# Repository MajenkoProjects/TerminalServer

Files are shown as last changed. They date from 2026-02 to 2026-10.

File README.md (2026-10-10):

Open-source Terminal Server
===========================

This is a small 6 port serial terminal server with ethernet, USB and WiFi
connectivity.

**NOTE: THIS IS WORK IN PROGRESS AND NOT COMPLETE YET**

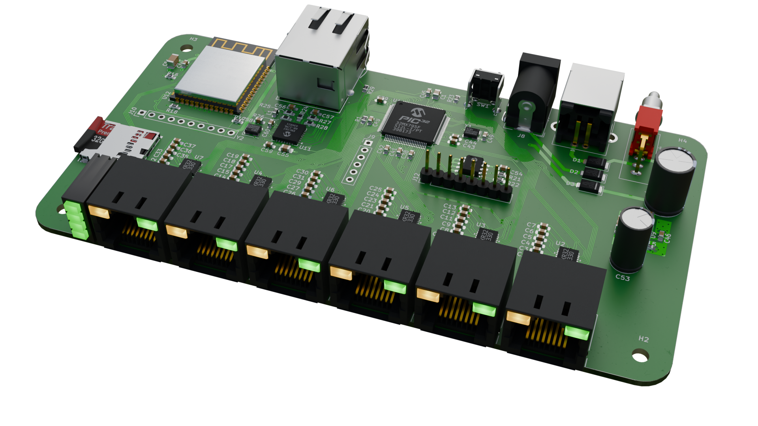
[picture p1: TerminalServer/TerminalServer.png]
Terminal Server


Current status:
---------------

* **Serial Ports:** Done
* **USB Ports:** Done
* **Ethernet:** Done
* **WiFi:** Done
* **Telnet in:** Done
* **Telnet out:** Done
* **TCP in:** Done
* **TU58 Emulation:** In Progress
* **TCP out:** Planned
* **PPP/SLIP:** Planned

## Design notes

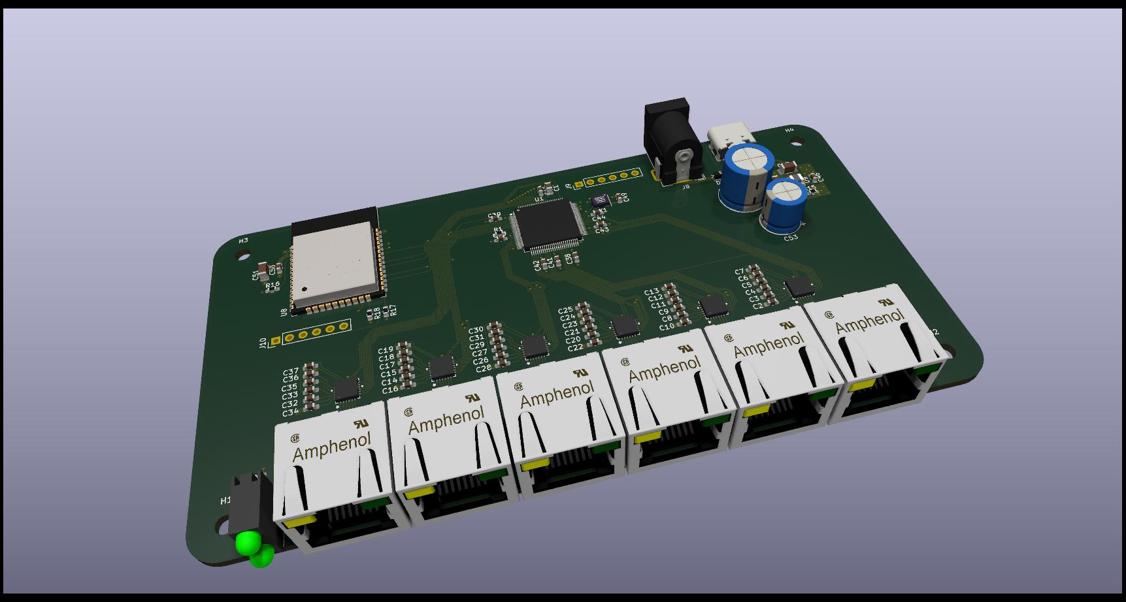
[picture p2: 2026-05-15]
TerminalServer/TerminalServer.jpg

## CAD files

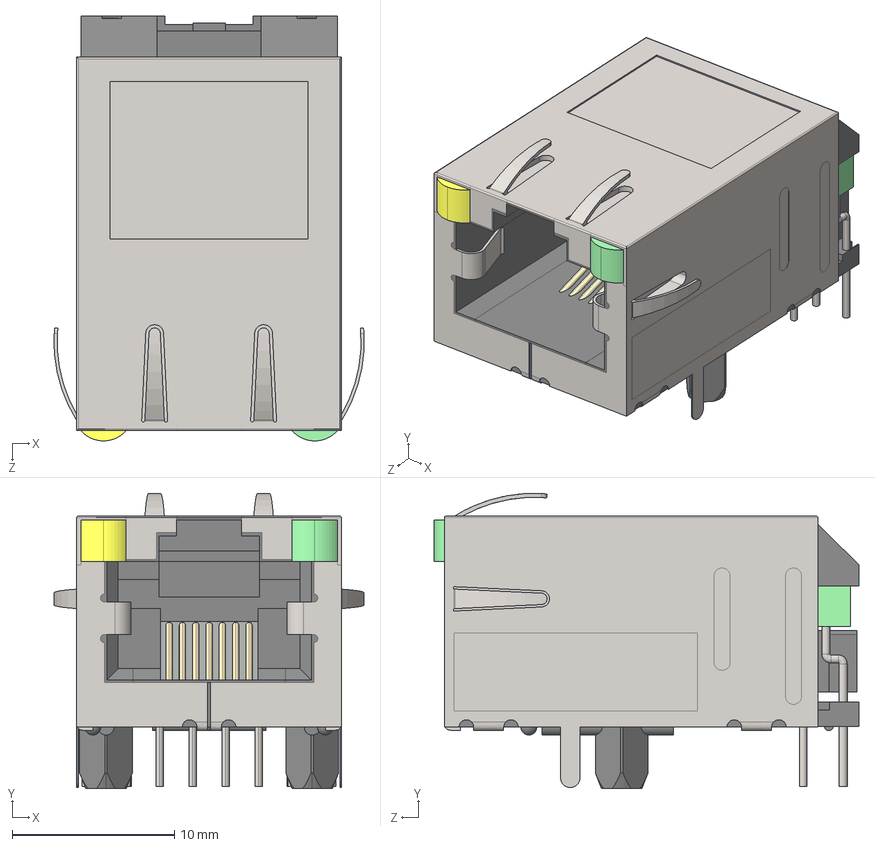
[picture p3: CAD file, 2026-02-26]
TerminalServer/Components/08B0-1D1T-06-F/3D/08B0-1D1T-06-F.stp
19.1 x 18.2 x 26.2 mm

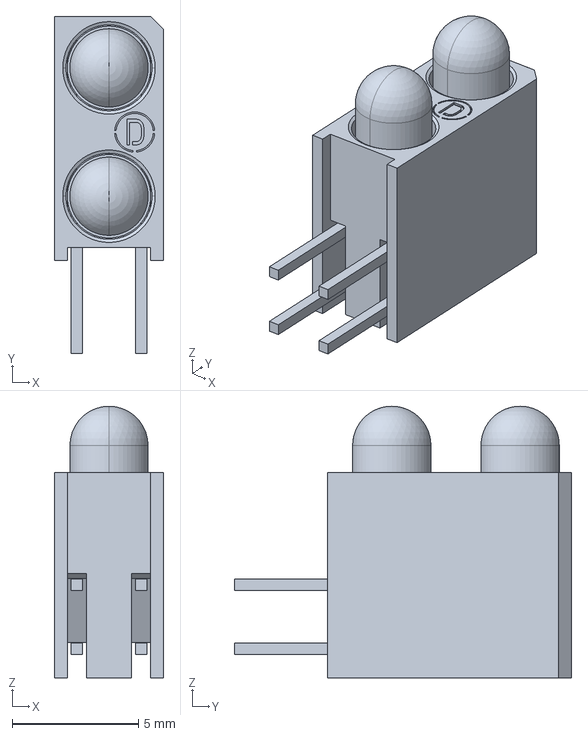
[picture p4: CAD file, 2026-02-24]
TerminalServer/Components/553-0121F/3D/553-0121F.stp
4.32 x 13.3 x 10.7 mm

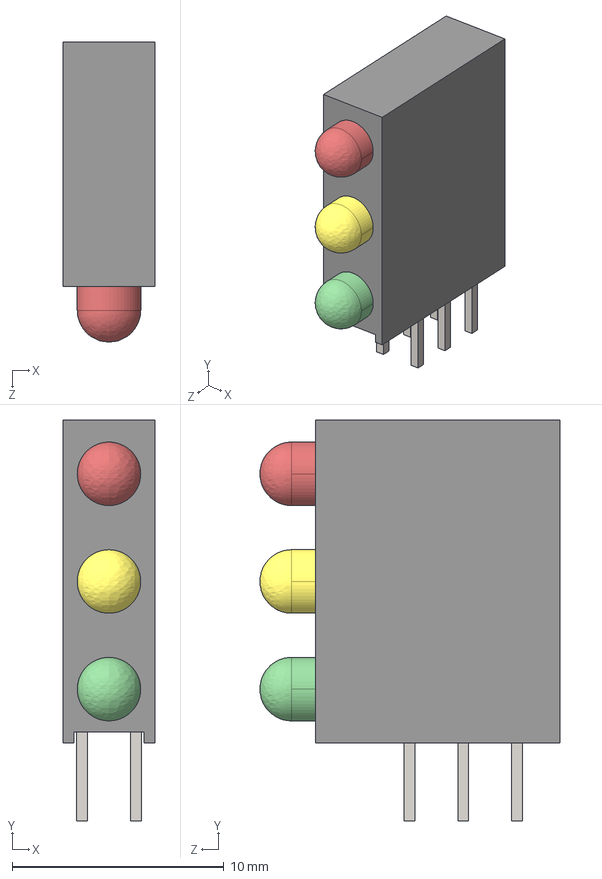
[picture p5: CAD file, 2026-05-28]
TerminalServer/Components/564-0100-132F/3D/564-0100-132F.stp
4.32 x 18.9 x 14.2 mm

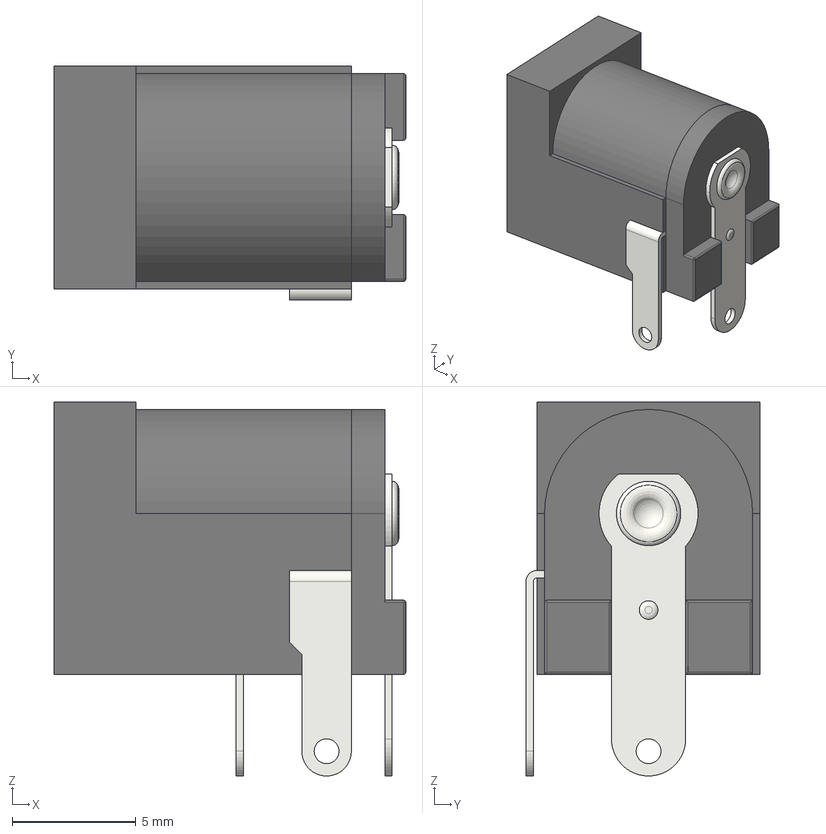
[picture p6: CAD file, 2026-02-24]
TerminalServer/Components/DC_Power_Jack_PCB_Mounted_2.1mm.step
14.2 x 9.45 x 15.1 mm
Plastic_Body_1of2
Plastic_Body_2of2
PIN_01
PIN_03
PIN_02
Boner

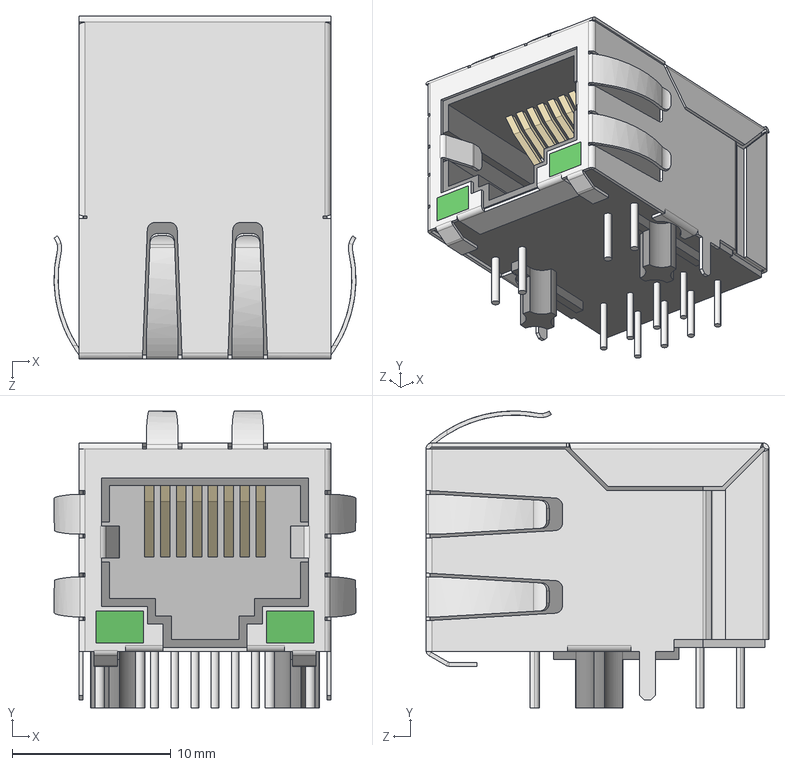
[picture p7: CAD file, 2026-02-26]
TerminalServer/Components/SI-60118-F/3D/SI-60118-F.stp
19.0 x 18.7 x 21.6 mm

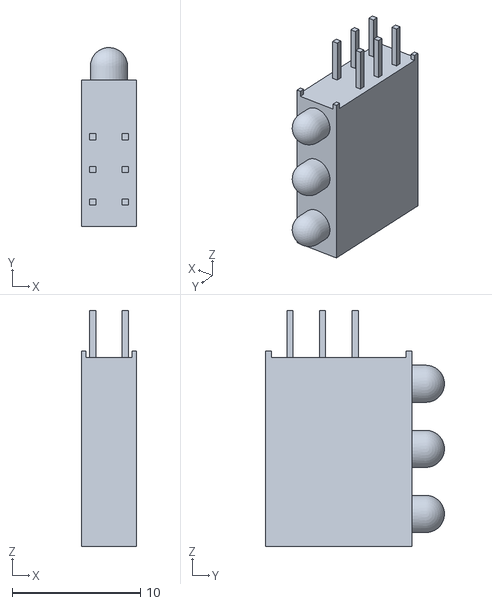
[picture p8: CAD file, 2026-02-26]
TerminalServer/Components/SSF-LXH340LYGID/3D/Unnamed-SSF-LXH340LYGID010.stl
4.32 x 14.0 x 18.4

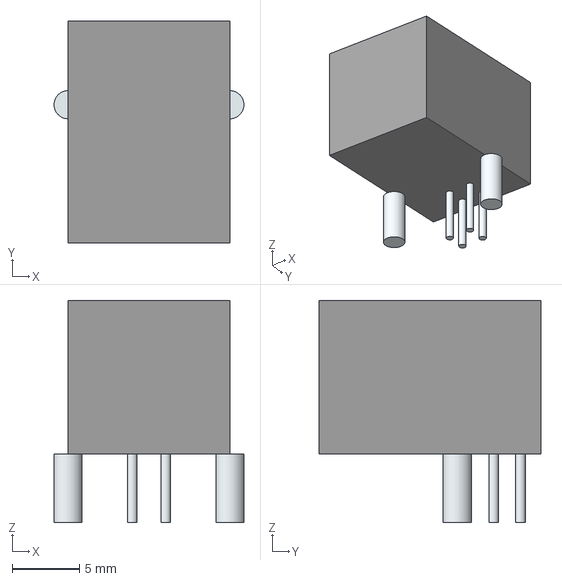
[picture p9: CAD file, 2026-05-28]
TerminalServer/Components/USB-B-S-RA-WT-SPCC/3D/USB-B-S-RA-WT-SPCC.stp
14.1 x 16.5 x 16.5 mm
Leads

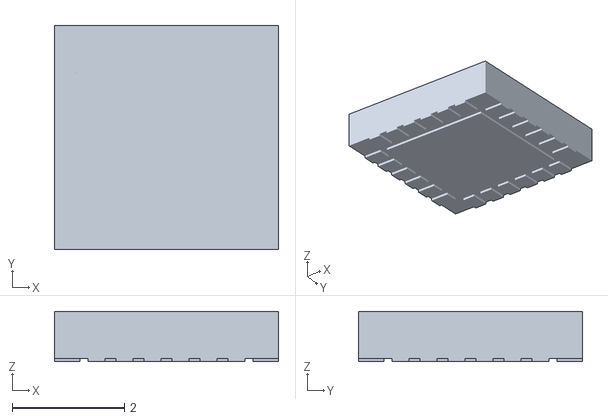
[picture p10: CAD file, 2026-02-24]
TerminalServer/Components/Unnamed-QFN_24.stl
3.99 x 3.99 x 0.892

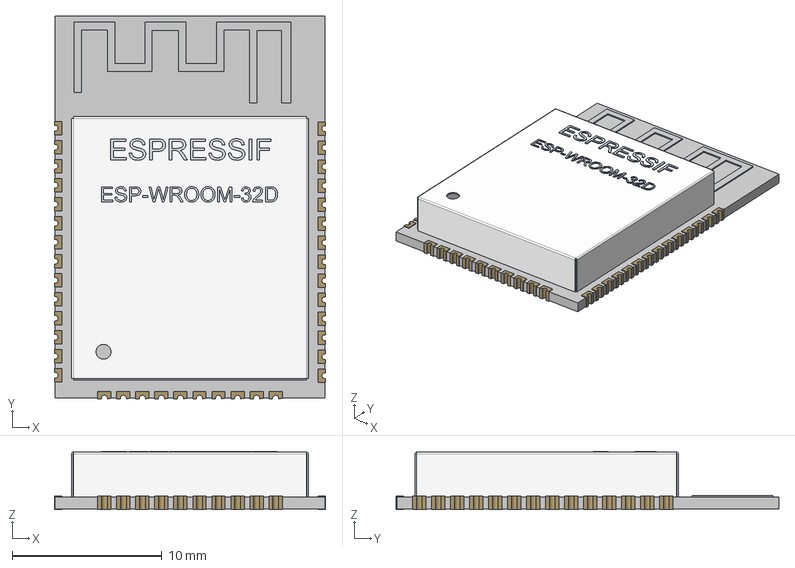
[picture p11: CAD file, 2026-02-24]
TerminalServer/Components/esp32_wroom_32D_module.step
18.1 x 25.6 x 3.90 mm
PCB_mince
Text_ESP32
Text_ESP033
Text_ESP034
Text_ESP035
Text_ESP036
Text_ESP037
Text_ESP038
Text_ESP039
Text_ESP040
Text_ESP041
Text_ESP042
Text_ESP043
Text_ESP044
Text_Espressif
Text_Espressif001
Text_Espressif002
Text_Espressif003
Text_Espressif004
Text_Espressif005
Text_Espressif006
Text_Espressif007
Text_Espressif008
pin_001 x 10
pin_011 x 14
pin_026 x 14

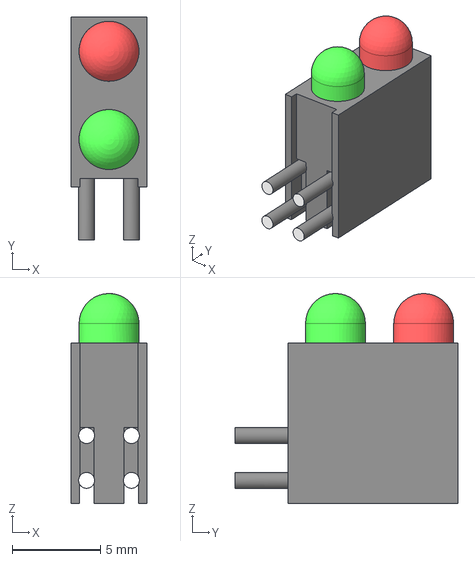
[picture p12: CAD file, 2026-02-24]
TerminalServer/Components/DUAL LED HOUSING 3mm.stp
4.32 x 12.7 x 11.9 mm

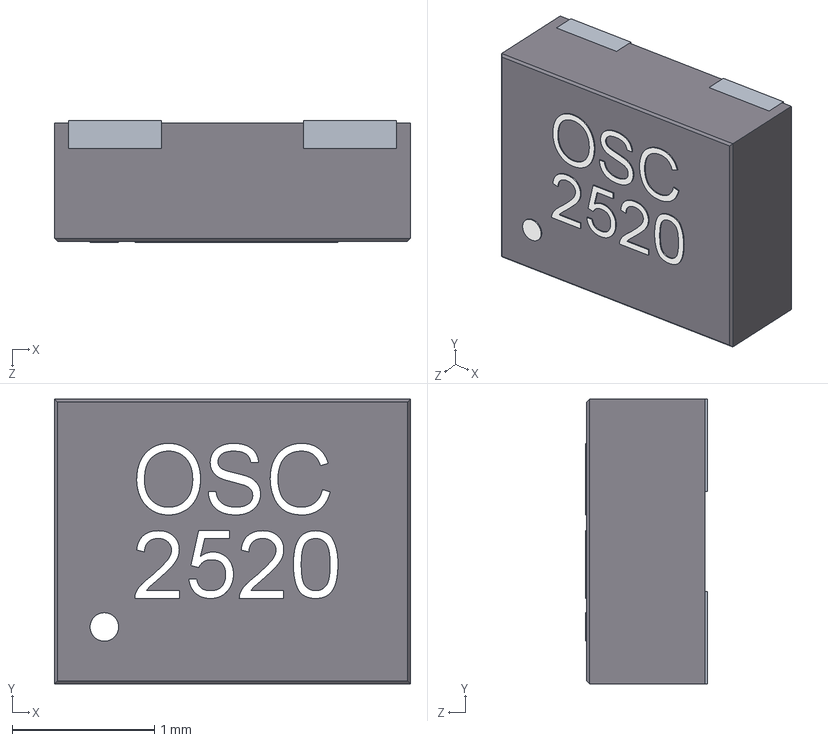
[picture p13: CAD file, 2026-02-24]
TerminalServer/Components/User Library-Oscillator2520-4pol-1.STEP
2.50 x 2.00 x 0.86 mm
Zylinder

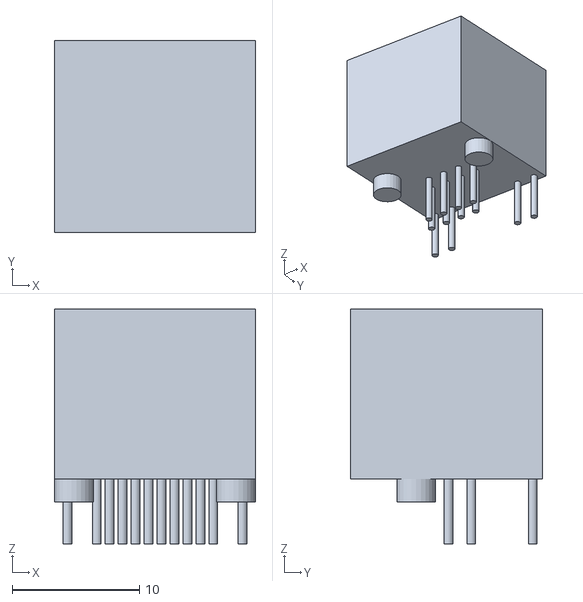
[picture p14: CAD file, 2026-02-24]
TerminalServer/Components/Unnamed-MTJ_88ARX1_LH.stl
15.8 x 15.1 x 18.4

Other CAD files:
TerminalServer/Components/553-0121F/3D/Unnamed-5530XXXF_SW0001.stl
TerminalServer/Components/SSF-LXH340LYGID/3D/SSF-LXH340LYGID.stp
TerminalServer/Components/Unnamed-DC_Power_Jack_PCB_Mounted_2.1mm.stl
TerminalServer/Components/esp32_wr_32_logo_module.step
TerminalServer/Components/QFN-24.iges
TerminalServer/Components/MTJ-88ARX1-LH.igs
TerminalServer/Components/12401610E4#2A/3D/12401610E4#2A.stl
TerminalServer/Components/12401610E4#2A/3D/12401610E4#2A.stp
TerminalServer/Components/217175-0001/3D/217175-0001.stl
TerminalServer/Components/217175-0001/3D/217175-0001.stp
TerminalServer/Components/503398-1892/3D/503398-1892.stl
TerminalServer/Components/503398-1892/3D/503398-1892.stp
TerminalServer/Components/564-0100-132F/3D/564-0100-132F.stl
TerminalServer/Components/TPS82130SILR.stp
TerminalServer/Components/USB-B-S-RA-WT-SPCC/3D/USB-B-S-RA-WT-SPCC.stl

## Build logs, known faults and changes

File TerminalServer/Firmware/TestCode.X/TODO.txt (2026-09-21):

Ports

    UART                Done
    USB                 Done
    Telnet In           Done
    Telnet Out          Done
    TCP In              Done
    TCP Out
    UDP In
    UDP Out

Functions

    Set terminal type (and map to tinfo)                    Done
    Set terminal local/forward/backward keys                Done
    Service definitions (name->port(s), name->telnet)
    Help

Misc

    Factory reset on hold button                            Done (30 second hold time)
    Bootloaderifcation
    mDNS                                                    Done (at least hostname is)

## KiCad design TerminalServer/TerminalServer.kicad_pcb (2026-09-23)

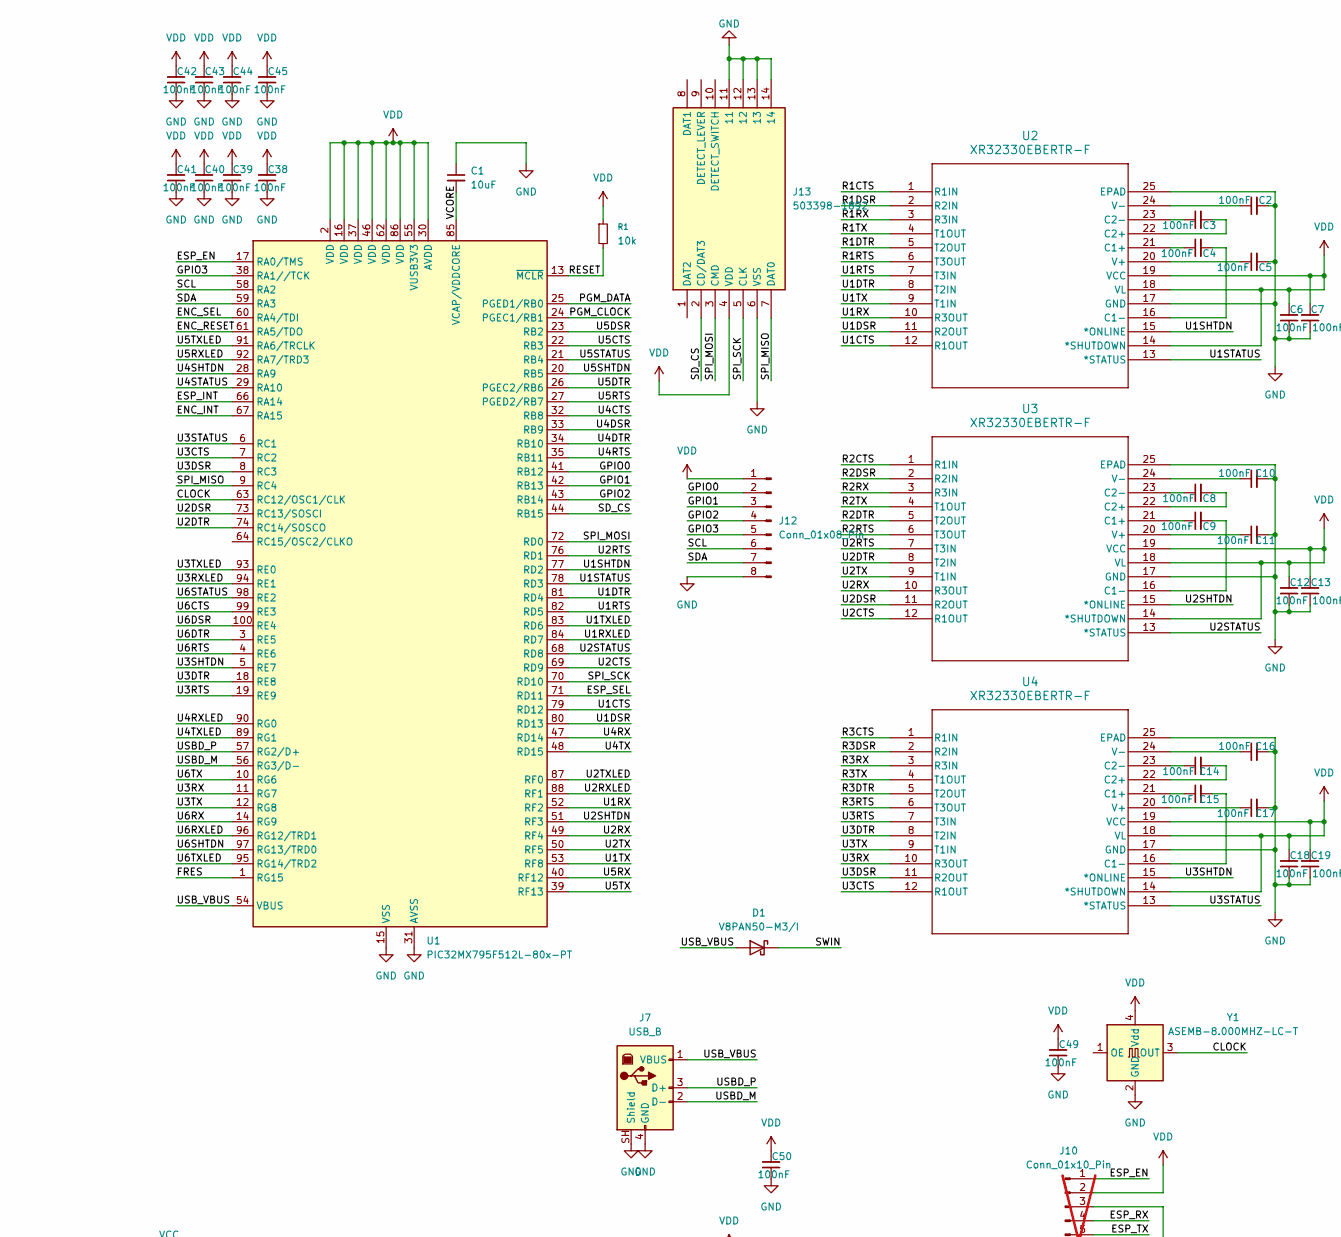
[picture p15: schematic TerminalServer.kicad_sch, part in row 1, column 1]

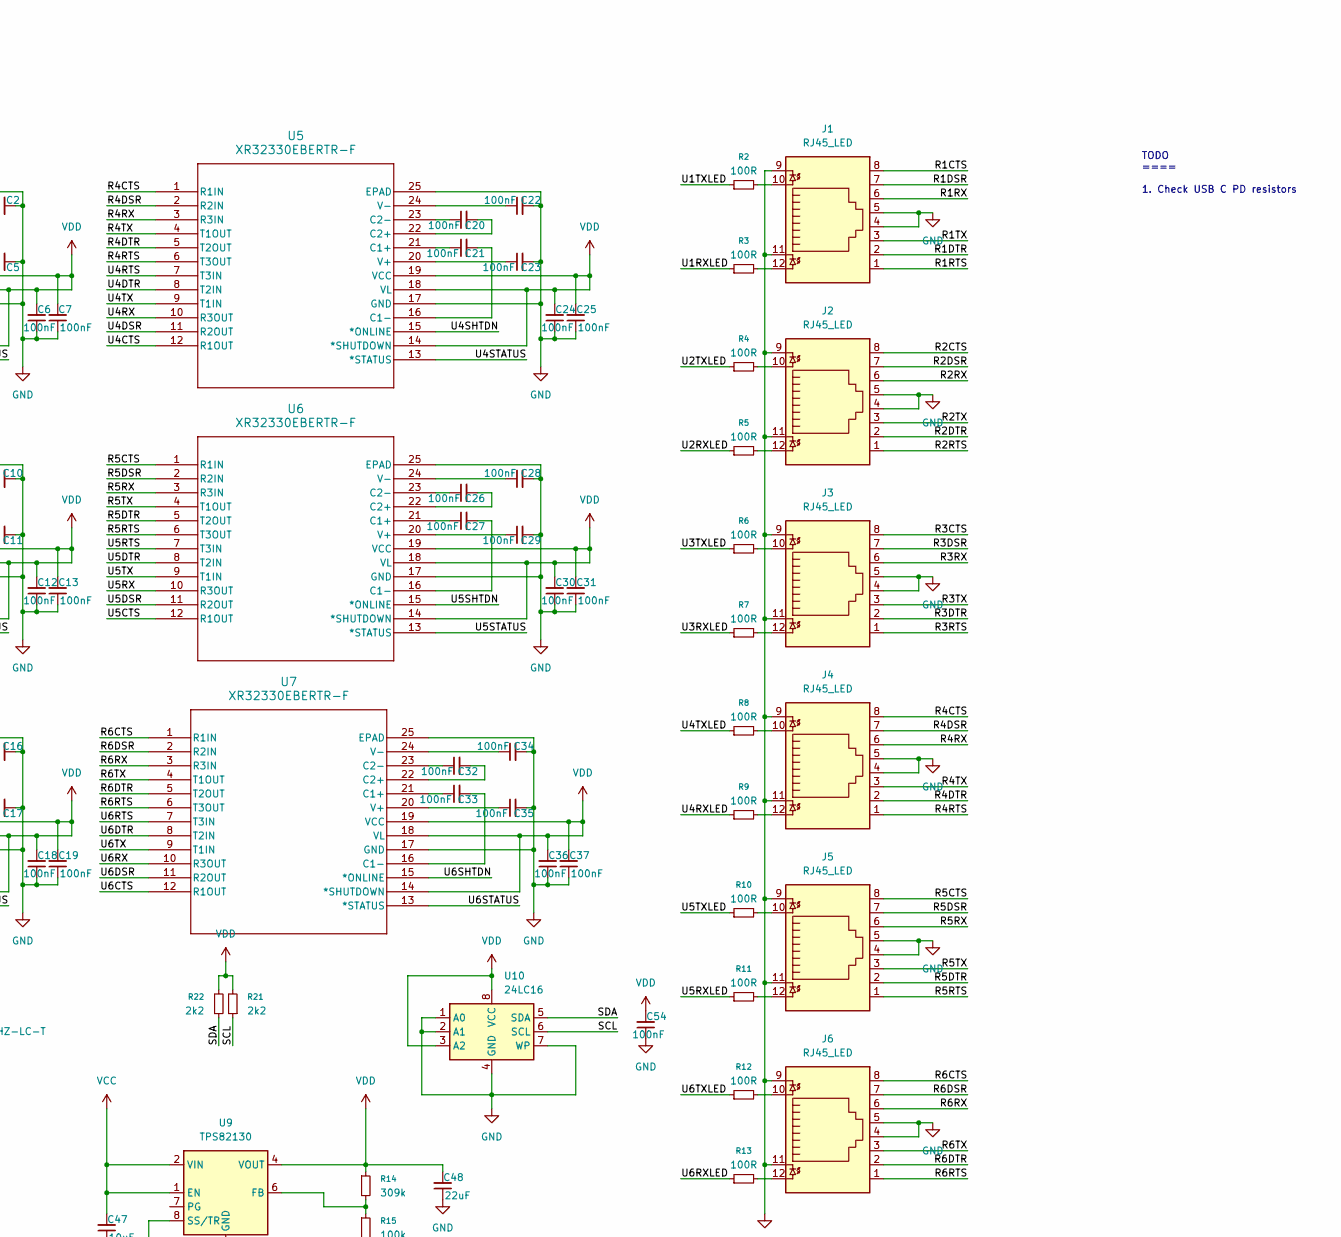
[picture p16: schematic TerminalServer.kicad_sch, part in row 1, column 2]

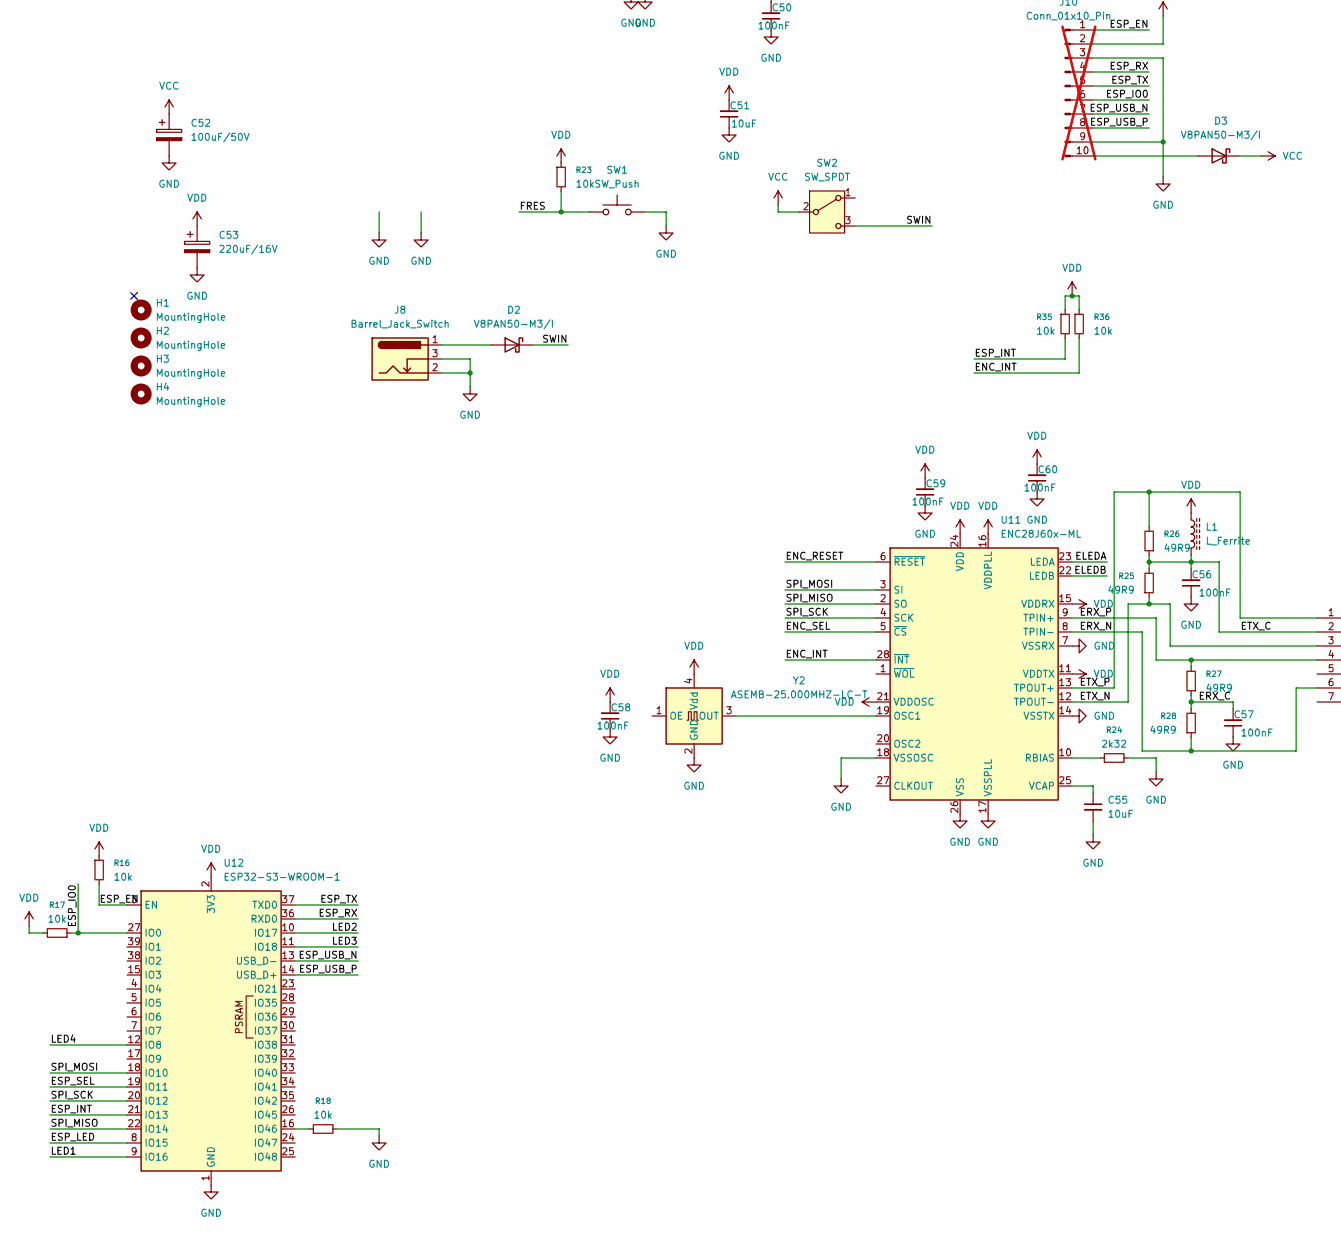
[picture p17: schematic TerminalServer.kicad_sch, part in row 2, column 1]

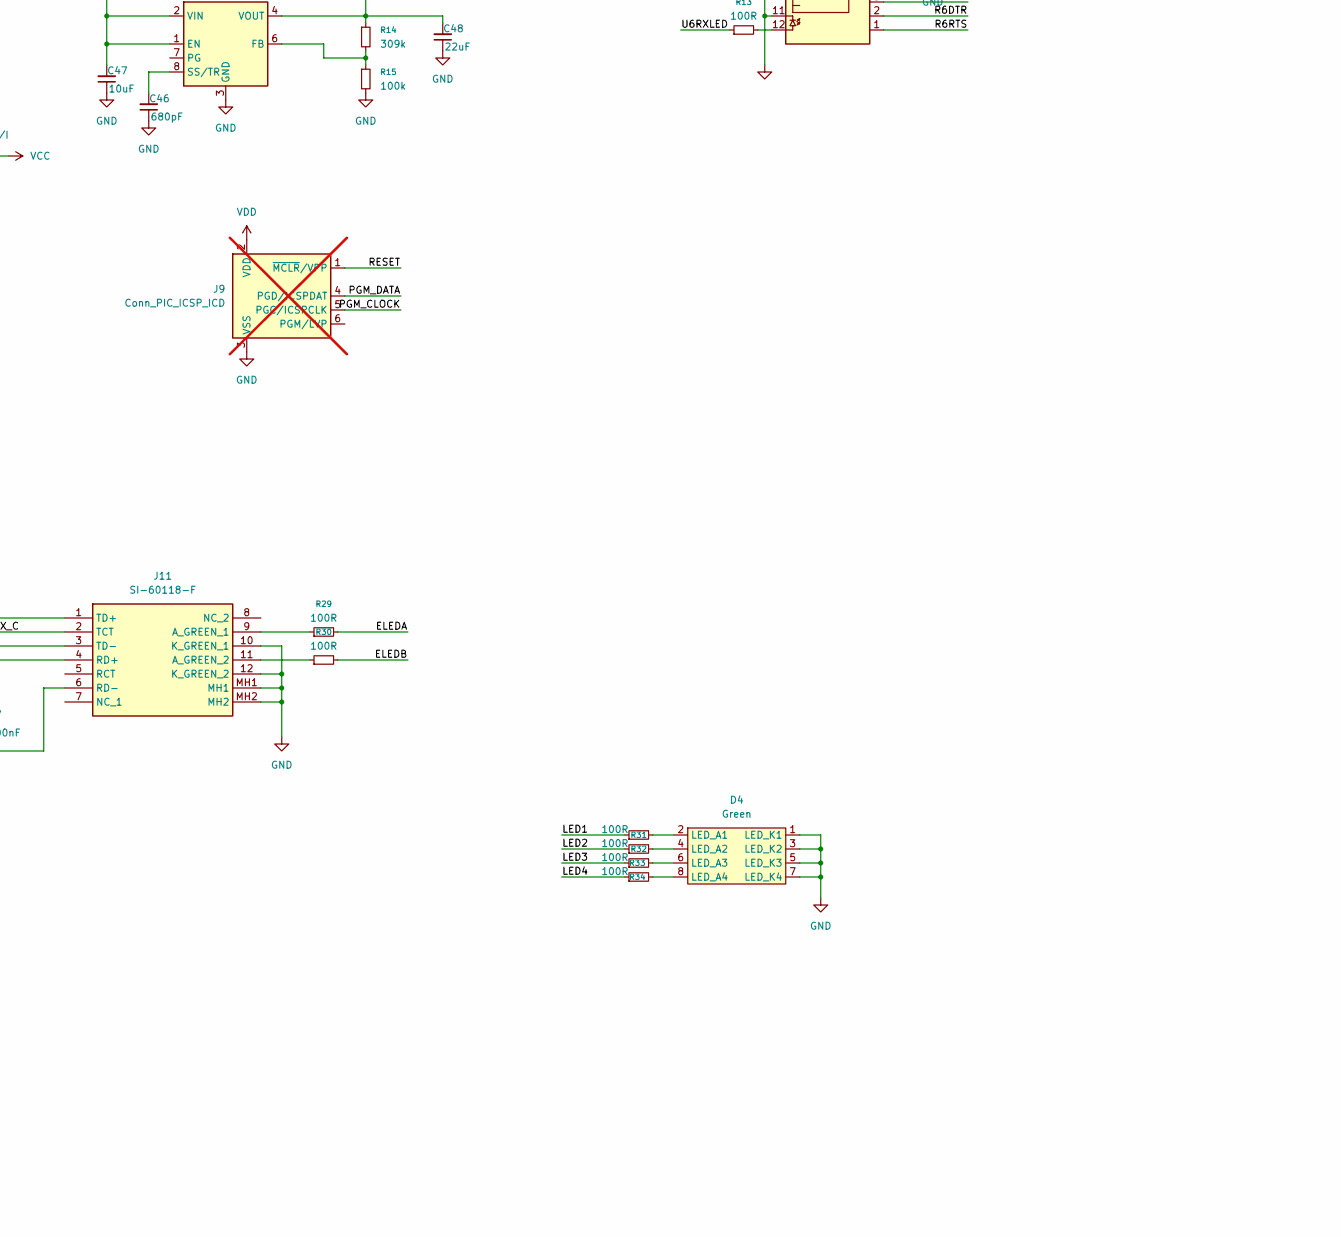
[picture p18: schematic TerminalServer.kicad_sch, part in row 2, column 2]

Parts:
C1, C55: 10uF; C_0805_2012Metric_Pad1.18x1.45mm_HandSolder
C2, C3, C4, C5, C6, C7, C8, C9, C10, C11, C12, C13, C14, C15, C16, C17, C18, C19, C20, C21, C22, C23, C24, C25, C26, C27, C28, C29, C30, C31, C32, C33, C34, C35, C36, C37, C38, C39, C40, C41, C42, C43, C44, C45, C49, C50, C54, C56, C57, C58, C59, C60: 100nF; C_0603_1608Metric_Pad1.08x0.95mm_HandSolder
C46: 680pF; C_0603_1608Metric_Pad1.08x0.95mm_HandSolder
C47, C51: 10uF; C_1206_3216Metric
C48: 22uF; C_1206_3216Metric
C52: 100uF/50V; CP_Radial_D8.0mm_P3.50mm; Part ESK107M050AG3AA
C53: 220uF/16V; CP_Radial_D6.3mm_P2.50mm; Part ESK227M016AE3EA
D1, D2, D3: V8PAN50-M3/I; Vishay_SMPA; Mouser 78-V8PAN50-M3/I
D4: Green; XL-DZ234SYGD-4; Mouser 604-WP914CK4GDT
H1, H2, H3, H4: MountingHole; MountingHole_3.2mm_M3
J1, J2, J3, J4, J5, J6: RJ45_LED; RJ45_MTJ-88ARX1-LH_ADM; Mouser 737-MTJ-88ARX1-LH
J7: USB_B; USB_B_OST_USB-B1HSxx_Horizontal; Mouser 200-USBBSFBTHFR
J8: Barrel_Jack_Switch; BarrelJack_Wuerth_6941xx301002; Mouser 710-694106301002
J9: Conn_PIC_ICSP_ICD; PinHeader_1x06_P2.54mm_Vertical; not fitted
J10: Conn_01x10_Pin; PinHeader_1x10_P2.54mm_Vertical; not fitted
J11: SI-60118-F; SI60118F; Mouser Part Number 530-SI-60118-F
J12: Conn_01x08_Pin; PinHeader_1x08_P2.54mm_Vertical
J13: 503398-1892; 5033981892; Mouser Part Number 538-503398-1892
L1: L_Ferrite; L_0603_1608Metric_Pad1.05x0.95mm_HandSolder
R1, R16, R17, R18, R23, R35, R36: 10k; R_0603_1608Metric_Pad0.98x0.95mm_HandSolder
R2, R3, R4, R5, R6, R7, R8, R9, R10, R11, R12, R13, R29, R30, R31, R32, R33, R34: 100R; R_0603_1608Metric_Pad0.98x0.95mm_HandSolder
R14: 309k; R_0603_1608Metric_Pad0.98x0.95mm_HandSolder
R15: 100k; R_0603_1608Metric_Pad0.98x0.95mm_HandSolder
R21, R22: 2k2; R_0603_1608Metric_Pad0.98x0.95mm_HandSolder
R24: 2k32; R_0603_1608Metric_Pad0.98x0.95mm_HandSolder
R25, R26, R27, R28: 49R9; R_0603_1608Metric_Pad0.98x0.95mm_HandSolder
SW1: SW_Push; SW_Tactile_SPST_Angled_PTS645Vx31-2LFS
SW2: SW_SPDT; 34ASP23B4M7RT
U1: PIC32MX795F512L-80x-PT; TQFP-100_12x12mm_P0.4mm; Mouser 579-PIC32MX795F512
U2, U3, U4, U5, U6, U7: XR32330EBERTR-F; QFN-24; Mouser 701-XR32330EBERTR-F
U9: TPS82130; Texas_SIL0008D_MicroSiP-8-1EP_2.8x3mm_P0.65mm_EP1.1x1.9mm_T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
U10: 24LC16; SOIC-8_3.9x4.9mm_P1.27mm
U11: ENC28J60x-ML; QFN-28-1EP_6x6mm_P0.65mm_EP4.25x4.25mm
U12: ESP32-S3-WROOM-1
Y1: ASEMB-8.000MHZ-LC-T; Oscillator_SMD_SiT_PQFN-4Pin_3.2x2.5mm
Y2: ASEMB-25.000MHZ-LC-T; Oscillator_SMD_SiT_PQFN-4Pin_3.2x2.5mm

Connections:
/CLOCK: U1.63 (RC12/OSC1/CLK), Y1.3 (OUT)
/ELEDA: R29.2, U11.23 (LEDA)
/ELEDB: R30.2, U11.22 (LEDB)
/ENC_INT: R36.2, U1.67 (RA15), U11.28 (~INT)
/ENC_RESET: U1.61 (RA5/TDO), U11.6 (~RESET)
/ENC_SEL: U1.60 (RA4/TDI), U11.5 (~CS)
/ERX_C: C57.2, R27.1, R28.2
/ERX_N: J11.6 (RD-), R28.1, U11.8 (TPIN-)
/ERX_P: J11.4 (RD+), R27.2, U11.9 (TPIN+)
/ESP_EN: J10.1, R16.2, U1.17 (RA0/TMS), U12.3 (EN)
/ESP_INT: R35.2, U1.66 (RA14), U12.21 (IO13)
/ESP_IO0: J10.6, R17.1, U12.27 (IO0)
/ESP_LED: U12.8 (IO15)
/ESP_RX: J10.4, U12.36 (RXD0)
/ESP_SEL: U1.71 (RD11), U12.19 (IO11)
/ESP_TX: J10.5, U12.37 (TXD0)
/ESP_USB_N: J10.7, U12.13 (USB_D-)
/ESP_USB_P: J10.8, U12.14 (USB_D+)
/ETX_C: C56.2, J11.2 (TCT), L1.2, R25.2, R26.1
/ETX_N: J11.3 (TD-), R25.1, U11.12 (TPOUT-)
/ETX_P: J11.1 (TD+), R26.2, U11.13 (TPOUT+)
/FRES: R23.2, SW1.1, U1.1 (RG15)
/GPIO0: J12.2, U1.41 (RB12)
/GPIO1: J12.3, U1.42 (RB13)
/GPIO2: J12.4, U1.43 (RB14)
/GPIO3: J12.5, U1.38 (RA1//TCK)
/LED1: R31.1, U12.9 (IO16)
/LED2: R32.1, U12.10 (IO17)
/LED3: R33.1, U12.11 (IO18)
/LED4: R34.1, U12.12 (IO8)
/PGM_CLOCK: J9.5 (PGC/ICSPCLK), U1.24 (PGEC1/RB1)
/PGM_DATA: J9.4 (PGD/ICSPDAT), U1.25 (PGED1/RB0)
/R1CTS: J1.8, U2.1 (R1IN)
/R1DSR: J1.7, U2.2 (R2IN)
/R1DTR: J1.2, U2.5 (T2OUT)
/R1RTS: J1.1, U2.6 (T3OUT)
/R1RX: J1.6, U2.3 (R3IN)
/R1TX: J1.3, U2.4 (T1OUT)
/R2CTS: J2.8, U3.1 (R1IN)
/R2DSR: J2.7, U3.2 (R2IN)
/R2DTR: J2.2, U3.5 (T2OUT)
/R2RTS: J2.1, U3.6 (T3OUT)
/R2RX: J2.6, U3.3 (R3IN)
/R2TX: J2.3, U3.4 (T1OUT)
/R3CTS: J3.8, U4.1 (R1IN)
/R3DSR: J3.7, U4.2 (R2IN)
/R3DTR: J3.2, U4.5 (T2OUT)
/R3RTS: J3.1, U4.6 (T3OUT)
/R3RX: J3.6, U4.3 (R3IN)
/R3TX: J3.3, U4.4 (T1OUT)
/R4CTS: J4.8, U5.1 (R1IN)
/R4DSR: J4.7, U5.2 (R2IN)
/R4DTR: J4.2, U5.5 (T2OUT)
/R4RTS: J4.1, U5.6 (T3OUT)
/R4RX: J4.6, U5.3 (R3IN)
/R4TX: J4.3, U5.4 (T1OUT)
/R5CTS: J5.8, U6.1 (R1IN)
/R5DSR: J5.7, U6.2 (R2IN)
/R5DTR: J5.2, U6.5 (T2OUT)
/R5RTS: J5.1, U6.6 (T3OUT)
/R5RX: J5.6, U6.3 (R3IN)
/R5TX: J5.3, U6.4 (T1OUT)
/R6CTS: J6.8, U7.1 (R1IN)
/R6DSR: J6.7, U7.2 (R2IN)
/R6DTR: J6.2, U7.5 (T2OUT)
/R6RTS: J6.1, U7.6 (T3OUT)
/R6RX: J6.6, U7.3 (R3IN)
/R6TX: J6.3, U7.4 (T1OUT)
/RESET: J9.1 (~MCLR/VPP), R1.2, U1.13 (~MCLR)
/SCL: J12.6, R21.1, U1.58 (RA2), U10.6 (SCL)
/SDA: J12.7, R22.1, U1.59 (RA3), U10.5 (SDA)
/SD_CS: J13.2 (CD/DAT3), U1.44 (RB15)
/SPI_MISO: J13.7 (DAT0), U1.9 (RC4), U11.2 (SO), U12.22 (IO14)
/SPI_MOSI: J13.3 (CMD), U1.72 (RD0), U11.3 (SI), U12.18 (IO10)
/SPI_SCK: J13.5 (CLK), U1.70 (RD10), U11.4 (SCK), U12.20 (IO12)
/SWIN: D1.1 (K), D2.1 (K), SW2.3 (C)
/U1CTS: U1.79 (RD12), U2.12 (R1OUT)
/U1DSR: U1.80 (RD13), U2.11 (R2OUT)
/U1DTR: U1.81 (RD4), U2.8 (T2IN)
/U1RTS: U1.82 (RD5), U2.7 (T3IN)
/U1RX: U1.52 (RF2), U2.10 (R3OUT)
/U1RXLED: R3.1, U1.84 (RD7)
/U1SHTDN: U1.77 (RD2), U2.15 (*ONLINE)
/U1STATUS: U1.78 (RD3), U2.13 (*STATUS)
/U1TX: U1.53 (RF8), U2.9 (T1IN)
/U1TXLED: R2.1, U1.83 (RD6)
/U2CTS: U1.69 (RD9), U3.12 (R1OUT)
/U2DSR: U1.73 (RC13/SOSCI), U3.11 (R2OUT)
/U2DTR: U1.74 (RC14/SOSCO), U3.8 (T2IN)
/U2RTS: U1.76 (RD1), U3.7 (T3IN)
/U2RX: U1.49 (RF4), U3.10 (R3OUT)
/U2RXLED: R5.1, U1.88 (RF1)
/U2SHTDN: U1.51 (RF3), U3.15 (*ONLINE)
/U2STATUS: U1.68 (RD8), U3.13 (*STATUS)
/U2TX: U1.50 (RF5), U3.9 (T1IN)
/U2TXLED: R4.1, U1.87 (RF0)
/U3CTS: U1.7 (RC2), U4.12 (R1OUT)
/U3DSR: U1.8 (RC3), U4.11 (R2OUT)
/U3DTR: U1.18 (RE8), U4.8 (T2IN)
/U3RTS: U1.19 (RE9), U4.7 (T3IN)
/U3RX: U1.11 (RG7), U4.10 (R3OUT)
/U3RXLED: R7.1, U1.94 (RE1)
/U3SHTDN: U1.5 (RE7), U4.15 (*ONLINE)
/U3STATUS: U1.6 (RC1), U4.13 (*STATUS)
/U3TX: U1.12 (RG8), U4.9 (T1IN)
/U3TXLED: R6.1, U1.93 (RE0)
/U4CTS: U1.32 (RB8), U5.12 (R1OUT)
/U4DSR: U1.33 (RB9), U5.11 (R2OUT)
/U4DTR: U1.34 (RB10), U5.8 (T2IN)
/U4RTS: U1.35 (RB11), U5.7 (T3IN)
/U4RX: U1.47 (RD14), U5.10 (R3OUT)
/U4RXLED: R9.1, U1.90 (RG0)
/U4SHTDN: U1.28 (RA9), U5.15 (*ONLINE)
/U4STATUS: U1.29 (RA10), U5.13 (*STATUS)
/U4TX: U1.48 (RD15), U5.9 (T1IN)
/U4TXLED: R8.1, U1.89 (RG1)
/U5CTS: U1.22 (RB3), U6.12 (R1OUT)
/U5DSR: U1.23 (RB2), U6.11 (R2OUT)
/U5DTR: U1.26 (PGEC2/RB6), U6.8 (T2IN)
/U5RTS: U1.27 (PGED2/RB7), U6.7 (T3IN)
/U5RX: U1.40 (RF12), U6.10 (R3OUT)
/U5RXLED: R11.1, U1.92 (RA7/TRD3)
/U5SHTDN: U1.20 (RB5), U6.15 (*ONLINE)
/U5STATUS: U1.21 (RB4), U6.13 (*STATUS)
/U5TX: U1.39 (RF13), U6.9 (T1IN)
/U5TXLED: R10.1, U1.91 (RA6/TRCLK)
/U6CTS: U1.99 (RE3), U7.12 (R1OUT)
/U6DSR: U1.100 (RE4), U7.11 (R2OUT)
/U6DTR: U1.3 (RE5), U7.8 (T2IN)
/U6RTS: U1.4 (RE6), U7.7 (T3IN)
/U6RX: U1.14 (RG9), U7.10 (R3OUT)
/U6RXLED: R13.1, U1.96 (RG12/TRD1)
/U6SHTDN: U1.97 (RG13/TRD0), U7.15 (*ONLINE)
/U6STATUS: U1.98 (RE2), U7.13 (*STATUS)
/U6TX: U1.10 (RG6), U7.9 (T1IN)
/U6TXLED: R12.1, U1.95 (RG14/TRD2)
/USBD_M: J7.2 (D-), U1.56 (RG3/D-)
/USBD_P: J7.3 (D+), U1.57 (RG2/D+)
/USB_VBUS: D1.2 (A), J7.1 (VBUS), U1.54 (VBUS)
/VCORE: C1.2, U1.85 (VCAP/VDDCORE)
GND: C1.1, C2.2, C5.2, C6.1, C7.1, C10.2, C11.2, C12.1, C13.1, C16.2, C17.2, C18.1, C19.1, C22.2, C23.2, C24.1, C25.1, C28.2, C29.2, C30.1, C31.1, C34.2, C35.2, C36.1, C37.1, C38.1, C39.1, C40.1, C41.1, C42.1, C43.1, C44.1, C45.1, C46.1, C47.1, C48.1, C49.1, C50.1, C51.1, C52.2, C53.2, C54.1, C55.2, C56.1, C57.1, C58.1, C59.1, C60.1, D4.1 (LED_K1), D4.3 (LED_K2), D4.5 (LED_K3), D4.7 (LED_K4), J1.4, J1.5, J1.9, J1.11, J2.4, J2.5, J2.9, J2.11, J3.4, J3.5, J3.9, J3.11, J4.4, J4.5, J4.9, J4.11, J5.4, J5.5, J5.9, J5.11, J6.4, J6.5, J6.9, J6.11, J7.4 (GND), J7.SH (Shield), J8.2, J8.3, J9.3 (VSS), J10.3, J10.9, J11.10 (K_GREEN_1), J11.12 (K_GREEN_2), J11.MH1, J11.MH2, J12.8, J13.6 (VSS), J13.11, J13.12, J13.13, J13.14, R15.2, R18.2, R24.2, SW1.2, U1.15 (VSS), U1.31 (AVSS), U1.36 (VSS), U1.45 (VSS), U1.65 (VSS), U1.75 (VSS), U2.17 (GND), U2.25 (EPAD), U3.17 (GND), U3.25 (EPAD), U4.17 (GND), U4.25 (EPAD), U5.17 (GND), U5.25 (EPAD), U6.17 (GND), U6.25 (EPAD), U7.17 (GND), U7.25 (EPAD), U9.3 (GND), U9.9 (GND), U10.1 (A0), U10.2 (A1), U10.4 (GND), U10.7 (WP), U11.7 (VSSRX), U11.14 (VSSTX), U11.17 (VSSPLL), U11.18 (VSSOSC), U11.26 (VSS), U12.1 (GND), U12.40 (GND), U12.41 (GND), Y1.2 (GND), Y2.2 (GND)
unnamed: D2.2 (A), J8.1
unnamed: D3.2 (A), J10.10
unnamed: D4.2 (LED_A1), R31.2
unnamed: D4.4 (LED_A2), R32.2
unnamed: D4.6 (LED_A3), R33.2
unnamed: D4.8 (LED_A4), R34.2
unnamed: J1.10, R2.2
unnamed: J1.12, R3.2
unnamed: J2.10, R4.2
unnamed: J2.12, R5.2
unnamed: J3.10, R6.2
unnamed: J3.12, R7.2
unnamed: J4.10, R8.2
unnamed: J4.12, R9.2
unnamed: J5.10, R10.2
unnamed: J5.12, R11.2
unnamed: J6.10, R12.2
unnamed: J6.12, R13.2
unnamed: J11.9 (A_GREEN_1), R29.1
unnamed: J11.11 (A_GREEN_2), R30.1
unnamed: C4.1, U2.21 (C1+)
unnamed: C4.2, U2.16 (C1-)
unnamed: C3.2, U2.22 (C2+)
unnamed: C3.1, U2.23 (C2-)
unnamed: C5.1, U2.20 (V+)
unnamed: C2.1, U2.24 (V-)
unnamed: C9.1, U3.21 (C1+)
unnamed: C9.2, U3.16 (C1-)
unnamed: C8.2, U3.22 (C2+)
unnamed: C8.1, U3.23 (C2-)
unnamed: C11.1, U3.20 (V+)
unnamed: C10.1, U3.24 (V-)
unnamed: C15.1, U4.21 (C1+)
unnamed: C15.2, U4.16 (C1-)
unnamed: C14.2, U4.22 (C2+)
unnamed: C14.1, U4.23 (C2-)
unnamed: C17.1, U4.20 (V+)
unnamed: C16.1, U4.24 (V-)
unnamed: C21.1, U5.21 (C1+)
unnamed: C21.2, U5.16 (C1-)
unnamed: C20.2, U5.22 (C2+)
unnamed: C20.1, U5.23 (C2-)
unnamed: C23.1, U5.20 (V+)
unnamed: C22.1, U5.24 (V-)
unnamed: C27.1, U6.21 (C1+)
unnamed: C27.2, U6.16 (C1-)
unnamed: C26.2, U6.22 (C2+)
unnamed: C26.1, U6.23 (C2-)
unnamed: C29.1, U6.20 (V+)
unnamed: C28.1, U6.24 (V-)
unnamed: C33.1, U7.21 (C1+)
unnamed: C33.2, U7.16 (C1-)
unnamed: C32.2, U7.22 (C2+)
unnamed: C32.1, U7.23 (C2-)
unnamed: C35.1, U7.20 (V+)
unnamed: C34.1, U7.24 (V-)
unnamed: R14.2, R15.1, U9.6 (FB)
unnamed: C46.2, U9.8 (SS/TR)
unnamed: U11.19 (OSC1), Y2.3 (OUT)
unnamed: R24.1, U11.10 (RBIAS)
unnamed: C55.1, U11.25 (VCAP)
unnamed: R18.1, U12.16 (IO46)
VCC: C47.2, C52.1, D3.1 (K), SW2.2 (B), U9.1 (EN), U9.2 (VIN)
VDD: C6.2, C7.2, C12.2, C13.2, C18.2, C19.2, C24.2, C25.2, C30.2, C31.2, C36.2, C37.2, C38.2, C39.2, C40.2, C41.2, C42.2, C43.2, C44.2, C45.2, C48.2, C49.2, C50.2, C51.2, C53.1, C54.2, C58.2, C59.2, C60.2, J9.2 (VDD), J10.2, J12.1, J13.4 (VDD), L1.1, R1.1, R14.1, R16.1, R17.2, R21.2, R22.2, R23.1, R35.1, R36.1, U1.2 (VDD), U1.16 (VDD), U1.30 (AVDD), U1.37 (VDD), U1.46 (VDD), U1.55 (VUSB3V3), U1.62 (VDD), U1.86 (VDD), U2.14 (*SHUTDOWN), U2.18 (VL), U2.19 (VCC), U3.14 (*SHUTDOWN), U3.18 (VL), U3.19 (VCC), U4.14 (*SHUTDOWN), U4.18 (VL), U4.19 (VCC), U5.14 (*SHUTDOWN), U5.18 (VL), U5.19 (VCC), U6.14 (*SHUTDOWN), U6.18 (VL), U6.19 (VCC), U7.14 (*SHUTDOWN), U7.18 (VL), U7.19 (VCC), U9.4 (VOUT), U9.5 (VOUT), U10.3 (A2), U10.8 (VCC), U11.11 (VDDTX), U11.15 (VDDRX), U11.16 (VDDPLL), U11.21 (VDDOSC), U11.24 (VDD), U12.2 (3V3), Y1.4 (Vdd), Y2.4 (Vdd)

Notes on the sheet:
TODO ==== 1. Check USB C PD resistors

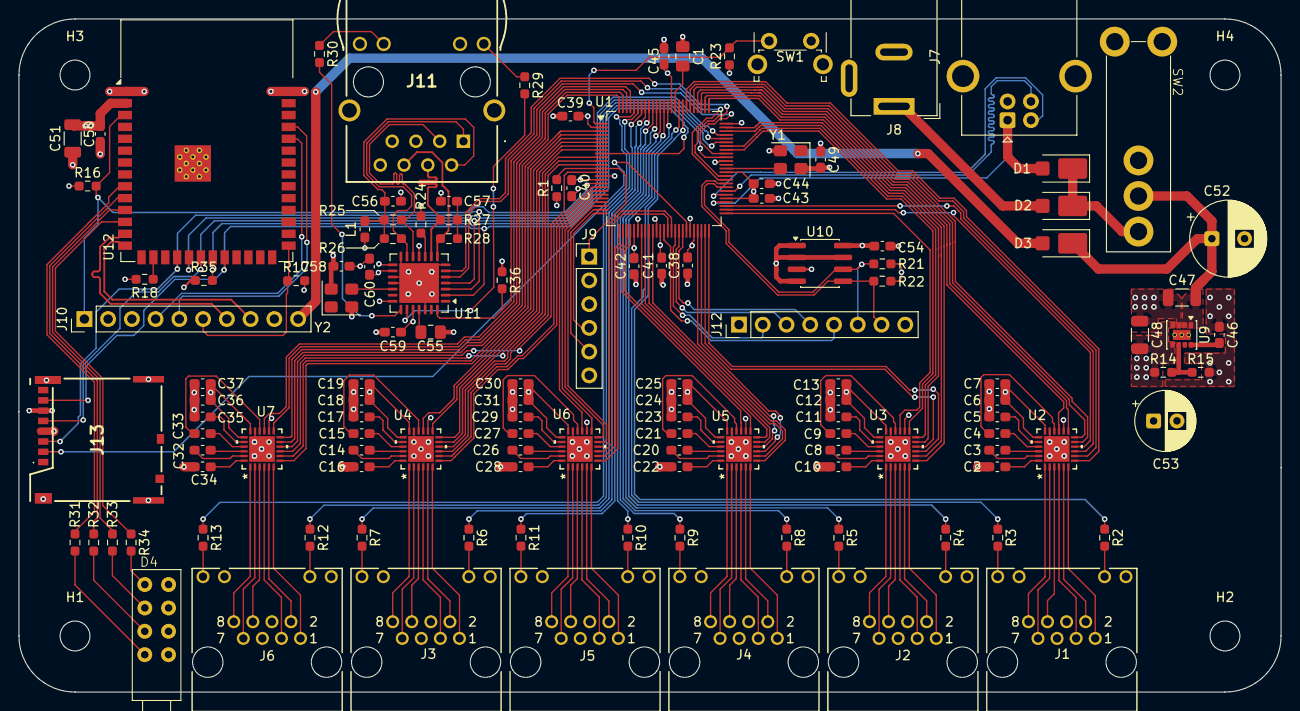
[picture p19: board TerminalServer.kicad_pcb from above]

Board: 4 copper layers, 135.0 x 72.0 mm, 131 parts (0 on the bottom side), 204 nets.

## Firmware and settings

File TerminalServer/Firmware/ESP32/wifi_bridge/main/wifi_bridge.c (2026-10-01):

#include <stdio.h>
#include <stdint.h>
#include <stddef.h>
#include <string.h>

#include "freertos/FreeRTOS.h"
#include "freertos/task.h"
#include "freertos/queue.h"
#include "freertos/event_groups.h"

#include "driver/spi_slave.h"
#include "driver/gpio.h"


#include "esp_wifi.h"
#include "esp_netif.h"
#include "esp_system.h"
#include "esp_event.h"
#include "esp_log.h"
#include "nvs_flash.h"
#include "lwip/err.h"
#include "lwip/sys.h"
#include "esp_private/wifi.h"
#include "esp_netif_net_stack.h"

#include "wifi_bridge.h"

#define GPIO_MOSI           10
#define GPIO_MISO           14
#define GPIO_SCLK           12
#define GPIO_CS             11
#define GPIO_INT            13
#define GPIO_LED1           16
#define GPIO_LED2           17
#define GPIO_LED3           18
#define GPIO_LED4           8



#define WIFI_CONNECTED_BIT BIT0
#define WIFI_FAIL_BIT      BIT1

struct mac {
    bool used;
    uint8_t address[6];
};

#define NUM_MACS 8

uint32_t activity_rx_led_ticks = 0;
uint32_t activity_tx_led_ticks = 0;

struct mac macs[NUM_MACS] = { 
    { // Broadcast
        .used = true,
        .address = { 0xFF, 0xFF, 0xFF, 0xFF, 0xFF, 0xFF }
    }
};


static const spi_bus_config_t buscfg = {
    .mosi_io_num = GPIO_MOSI,
    .miso_io_num = GPIO_MISO,
    .sclk_io_num = GPIO_SCLK,
    .quadwp_io_num = -1,
    .quadhd_io_num = -1,
};

enum state {
	STATE_INIT = 0,
	STATE_INIT_SPI,
	STATE_INIT_WIFI,
	STATE_QUEUE_XFER,
	STATE_WAIT_XFER,
	STATE_GOT_XFER,
};

wifi_status_t wifi_status = {
    .state = WIFI_IDLE
};

enum state state = STATE_INIT;
bool first_mac_set = false;

QueueHandle_t wifi_to_spi_queue;

void init_io() {
    gpio_config_t io_conf = {
        .pin_bit_mask = (1ULL << GPIO_INT),
        .mode = GPIO_MODE_OUTPUT,
        .pull_up_en = GPIO_PULLUP_DISABLE,
        .pull_down_en = GPIO_PULLDOWN_DISABLE,
        .intr_type = GPIO_INTR_DISABLE,
    };
    gpio_config(&io_conf);

    io_conf.pin_bit_mask = (1ULL << GPIO_LED1);
    gpio_config(&io_conf);

    io_conf.pin_bit_mask = (1ULL << GPIO_LED2);
    gpio_config(&io_conf);

    io_conf.pin_bit_mask = (1ULL << GPIO_LED3);
    gpio_config(&io_conf);

    io_conf.pin_bit_mask = (1ULL << GPIO_LED4);
    gpio_config(&io_conf);

    gpio_set_level(GPIO_INT, 1);
    gpio_set_level(GPIO_LED1, 0);
    gpio_set_level(GPIO_LED2, 0);
    gpio_set_level(GPIO_LED3, 0);
    gpio_set_level(GPIO_LED4, 1);
}


void my_post_setup_cb(spi_slave_transaction_t *trans)
{
}

void my_post_trans_cb(spi_slave_transaction_t *trans)
{
}

 
static const spi_slave_interface_config_t slvcfg = {
    .mode = 0,
    .spics_io_num = GPIO_CS,
    .queue_size = 2,
    .flags = 0,
    .post_setup_cb = my_post_setup_cb,
    .post_trans_cb = my_post_trans_cb
};


//static EventGroupHandle_t s_wifi_event_group;


// Callback signature required by ESP-IDF Wi-Fi driver
static esp_err_t wifi_l2_rx_cb(void *buffer, uint16_t len, void *eb)
{
    if (buffer && len > 0) {
        
        uint8_t *buf = (uint8_t *)buffer;
        bool allowed = false;
        for (int i = 0; i < NUM_MACS; i++) {
            if (macs[i].used == false) continue;
            if (    (macs[i].address[0] == buf[0]) &&
                    (macs[i].address[1] == buf[1]) &&
                    (macs[i].address[2] == buf[2]) &&
                    (macs[i].address[3] == buf[3]) &&
                    (macs[i].address[4] == buf[4]) &&
                    (macs[i].address[5] == buf[5])) {
                allowed = true;
                break;
            }
        }

        if (!allowed) {
            //printf("Packet rejected\r\n");
            esp_wifi_internal_free_rx_buffer(eb);
            return ESP_OK;        
        }

        //printf("RX:%lu\r\n", xTaskGetTickCount());
        
        gpio_set_level(GPIO_LED2, 1);
        activity_rx_led_ticks = xTaskGetTickCount();

        gpio_set_level(GPIO_INT, 0);
        l2_packet_t pkt;
        pkt.length = len;
        pkt.payload = malloc(len);
        memcpy(pkt.payload, buffer, len);

        if (xQueueSendToBack(wifi_to_spi_queue, &pkt, 0) != pdTRUE) {
            free(pkt.payload); // Queue full, drop packet
        }
    }

    // CRITICAL: You MUST free the internal Wi-Fi RX buffer back to the driver
    esp_wifi_internal_free_rx_buffer(eb);
    return ESP_OK;
}

static void event_handler(void* arg, esp_event_base_t event_base,
        int32_t event_id, void* event_data) {
    if (event_base == WIFI_EVENT && event_id == WIFI_EVENT_STA_START) {
    } else if (event_base == WIFI_EVENT && event_id == WIFI_EVENT_STA_DISCONNECTED) {
        gpio_set_level(GPIO_LED1, 0);
        //printf("WiFi disconnected.\r\n");
        wifi_status.state = WIFI_DISCONNECTED;
        wifi_status.link = 0;
    } else if (event_base == WIFI_EVENT && event_id == WIFI_EVENT_STA_CONNECTED) {
        gpio_set_level(GPIO_LED1, 1);
        //printf("WiFi connected.\r\n");
        ESP_ERROR_CHECK(esp_wifi_internal_reg_rxcb(WIFI_IF_STA, wifi_l2_rx_cb));
        wifi_status.link = 1;
        wifi_status.state = WIFI_CONNECTED;
    }
}

#define RCV_HOST SPI2_HOST

esp_err_t send_raw_wifi_frame(void *netif, void *buffer, size_t len)
{
    return esp_wifi_internal_tx(WIFI_IF_STA, (void *)buffer, len);
}

void wifi_init_sta(void)
{
// 1. Initialize TCP/IP netif stack FIRST
    ESP_ERROR_CHECK(esp_netif_init());

    // 2. Create default system event loop required by esp_netif Wi-Fi handlers
    esp_err_t err = esp_event_loop_create_default();
    if (err != ESP_OK && err != ESP_ERR_INVALID_STATE) {
        ESP_ERROR_CHECK(err); // Ignore if default loop was already created elsewhere
    }

    // 3. Create default STA netif instance
    esp_netif_t *sta_netif = esp_netif_create_default_wifi_sta();
    assert(sta_netif);
    
    esp_netif_dhcpc_stop(sta_netif);

    // 4. Initialize Wi-Fi driver with default config
    wifi_init_config_t cfg = WIFI_INIT_CONFIG_DEFAULT();
    cfg.nvs_enable = 0;
    ESP_ERROR_CHECK(esp_wifi_init(&cfg));


    
    
    
    // Register L2 hook AFTER starting Wi-Fi
/*
    s_wifi_event_group = xEventGroupCreate();


    ESP_ERROR_CHECK(esp_event_loop_create_default());
    esp_netif_create_default_wifi_sta();

    wifi_init_config_t cfg = WIFI_INIT_CONFIG_DEFAULT();
    cfg.nvs_enable = 0;

    ESP_ERROR_CHECK(esp_wifi_init(&cfg));
*/
    esp_event_handler_instance_t instance_any_id;
    esp_event_handler_instance_t instance_got_ip;
    ESP_ERROR_CHECK(esp_event_handler_instance_register(WIFI_EVENT,
                                                        ESP_EVENT_ANY_ID,
                                                        &event_handler,
                                                        NULL,
                                                        &instance_any_id));
    ESP_ERROR_CHECK(esp_event_handler_instance_register(IP_EVENT,
                                                        IP_EVENT_STA_GOT_IP,
                                                        &event_handler,
                                                        NULL,
                                                        &instance_got_ip));

    /*
    wifi_config_t wifi_config = {
        .sta = {
            .ssid = "",
            .password = "",
        },
    };
    ESP_ERROR_CHECK(esp_wifi_set_mode(WIFI_MODE_STA) );
    ESP_ERROR_CHECK(esp_wifi_set_config(WIFI_IF_STA, &wifi_config) );
    ESP_ERROR_CHECK(esp_wifi_start() );
*/
    
    
        // 5. Set mode to STA and start Wi-Fi
    ESP_ERROR_CHECK(esp_wifi_set_mode(WIFI_MODE_STA));
    ESP_ERROR_CHECK(esp_wifi_start());

    esp_wifi_set_ps(WIFI_PS_NONE);
    
    // 6. Register L2 RX callback AFTER esp_wifi_start()
    ESP_ERROR_CHECK(esp_wifi_internal_reg_rxcb(WIFI_IF_STA, wifi_l2_rx_cb));
	return;
}


void app_main(void)
{
	char ssid[33] = {0};
	char psk[65] = {0};
	int bytes = 0;
	uint8_t *tx = NULL;
	uint8_t *rx = NULL;

    uint8_t *txA = NULL;
    uint8_t *txB = NULL;

    uint8_t *rxA = NULL;
    uint8_t *rxB = NULL;

    
    init_io();
	spi_slave_transaction_t transactionA = { 0 };
	spi_slave_transaction_t transactionB = { 0 };
    spi_slave_transaction_t *transaction = NULL;
    
	transactionA.length = SPI_MAX_SIZE * 8;
	transactionB.length = SPI_MAX_SIZE * 8;


	spi_slave_transaction_t *result = NULL;
    wifi_to_spi_queue = xQueueCreate(32, sizeof(l2_packet_t));
    l2_packet_t pkt;
    
    int tmpint;
    
    while (1) {

        
        if (activity_rx_led_ticks > 0) {
            if ((xTaskGetTickCount() - activity_rx_led_ticks) > 10) {
                gpio_set_level(GPIO_LED2, 0);
                activity_rx_led_ticks = 0;
            }
        }

        if (activity_tx_led_ticks > 0) {
            if ((xTaskGetTickCount() - activity_tx_led_ticks) > 10) {
                gpio_set_level(GPIO_LED3, 0);
                activity_tx_led_ticks = 0;
            }
        }


        if (uxQueueMessagesWaiting(wifi_to_spi_queue) == 0) {
            gpio_set_level(GPIO_INT, 1);
        }

        
		switch (state) {
			case STATE_INIT:
				//printf("ESP32 WiFi MAC Bridge (c) 2026 Majenko Technologies\r\n");
				state = STATE_INIT_SPI;
				break;

			case STATE_INIT_SPI:
				gpio_set_pull_mode(GPIO_MOSI, GPIO_PULLUP_ONLY);
				gpio_set_pull_mode(GPIO_SCLK, GPIO_PULLUP_ONLY);
				gpio_set_pull_mode(GPIO_CS, GPIO_PULLUP_ONLY);
				spi_slave_initialize(RCV_HOST, &buscfg, &slvcfg, SPI_DMA_CH_AUTO);
				transactionA.tx_buffer = txA = spi_bus_dma_memory_alloc(RCV_HOST, SPI_MAX_SIZE, 0);
				transactionA.rx_buffer = rxA = spi_bus_dma_memory_alloc(RCV_HOST, SPI_MAX_SIZE, 0);
				transactionB.tx_buffer = txB = spi_bus_dma_memory_alloc(RCV_HOST, SPI_MAX_SIZE, 0);
				transactionB.rx_buffer = rxB = spi_bus_dma_memory_alloc(RCV_HOST, SPI_MAX_SIZE, 0);

                if ((transactionA.tx_buffer == NULL) ||
                 (transactionB.tx_buffer == NULL) ||
                 (transactionA.rx_buffer == NULL) ||
                 (transactionB.rx_buffer == NULL)) {
                    printf("No memory\r\n");
                    while(1);
                }
				//printf("SPI interface configured\r\n");
                tx = txA;
                rx = rxA;
                transaction = &transactionA;
				state = STATE_INIT_WIFI;
				break;

			case STATE_INIT_WIFI:
				wifi_init_sta();
                //printf("WiFI interface configured\r\n");
				state = STATE_QUEUE_XFER;
				break;

			case STATE_QUEUE_XFER:
                //printf("Queued initial transfer\r\n");
				spi_slave_queue_trans(RCV_HOST, transaction, 1);
                state = STATE_WAIT_XFER;
				break;

			case STATE_WAIT_XFER:
				if (spi_slave_get_trans_result(RCV_HOST, &result, 1) == ESP_OK) {
                    //printf("Got transfer.\r\n");
                    if (result == &transactionA) {
                        transaction = &transactionB;
                        //printf("Transfer is A\r\n");
                    } else {
                        transaction = &transactionA;
                        //printf("Transfer is B\r\n");
                    }
                    tx = (uint8_t *)transaction->tx_buffer;
                    rx = (uint8_t *)result->rx_buffer;
                    bytes = result->trans_len / 8;
					state = STATE_GOT_XFER;
                    //printf("Code %02x\r\n", rx[0]);
				}
				break;

			case STATE_GOT_XFER:
				switch (rx[0]) {
                    case REG_RESET:
                        spi_slave_queue_trans(RCV_HOST, transaction, 1);
                        memset(ssid, 0, 33);
                        memset(psk, 0, 65);
                        xQueueReset(wifi_to_spi_queue);
                        esp_wifi_stop();
                        wifi_status.state = WIFI_IDLE;
                        break;
                        
					case REG_SSID:
                        spi_slave_queue_trans(RCV_HOST, transaction, 1);
						if (bytes > 1) {
							memset(ssid, 0, 33);
							memcpy(ssid, &rx[1], bytes - 1);
                            //printf("SSID: %s\r\n", ssid);
						}
						break;
					case REG_PSK:
                        spi_slave_queue_trans(RCV_HOST, transaction, 1);
						if (bytes > 1) {
							memset(psk, 0, 65);
							memcpy(psk, &rx[1], bytes - 1);
                            //printf("PSK: %s\r\n", psk);
						}
						break;
					case REG_STATUS:
                        esp_wifi_sta_get_rssi(&tmpint);
                        wifi_status.rssi = htonl(tmpint);
                        wifi_status.pending = uxQueueMessagesWaiting(wifi_to_spi_queue);
                        if (wifi_status.pending > 0) {
                            xQueuePeek(wifi_to_spi_queue, &pkt, 1);
                            wifi_status.nextsize = htons(pkt.length);
                        } else {
                            wifi_status.nextsize = 0;
                        }
                        memcpy(tx, wifi_status.val, sizeof(wifi_status_t));
                        spi_slave_queue_trans(RCV_HOST, transaction, 1);
						break;
					case REG_RBSTAT:
                        tx[0] = uxQueueMessagesWaiting(wifi_to_spi_queue);
                        if (tx[0] > 0) {
                            xQueuePeek(wifi_to_spi_queue, &pkt, 1);
                            tx[1] = pkt.length >> 8;
                            tx[2] = pkt.length;
                            //printf("%d in queue, next is %d\r\n", tx[0], pkt.length);
                        } else {
                            tx[1] = 0;
                            tx[2] = 0;
                        }
                        spi_slave_queue_trans(RCV_HOST, transaction, 1);
						break;
					case REG_RPACKET:
                        if (xQueueReceive(wifi_to_spi_queue, &pkt, 1) == pdTRUE) {
                            tx[0] = pkt.length >> 8;
                            tx[1] = pkt.length;
                            memcpy(&tx[2], pkt.payload, pkt.length);
                            free(pkt.payload);
                            //printf("XF:%lu\r\n", xTaskGetTickCount());
                        }
                        spi_slave_queue_trans(RCV_HOST, transaction, 1);
						break;
					case REG_WPACKET:
                        spi_slave_queue_trans(RCV_HOST, transaction, 1);

                        ESP_ERROR_CHECK(esp_wifi_internal_tx(WIFI_IF_STA, (void *)&rx[1], bytes - 1));
                        gpio_set_level(GPIO_LED3, 1);
                        activity_tx_led_ticks = xTaskGetTickCount();
                        break;
					case REG_ADDMAC:
                        spi_slave_queue_trans(RCV_HOST, transaction, 1);
                        if (bytes == 7) {
                            if (!first_mac_set) {
                                esp_wifi_set_mac(WIFI_IF_STA, &rx[1]);
                                first_mac_set = true;
                            }
                            for (int i = 0; i < NUM_MACS; i++) {
                                if (macs[i].used == false) {
                                    macs[i].address[0] = rx[1];
                                    macs[i].address[1] = rx[2];
                                    macs[i].address[2] = rx[3];
                                    macs[i].address[3] = rx[4];
                                    macs[i].address[4] = rx[5];
                                    macs[i].address[5] = rx[6];
                                    macs[i].used = true;
                                    break;
                                }
                            }
                        }
						break;
					case REG_DELMAC:
                        spi_slave_queue_trans(RCV_HOST, transaction, 1);
						break;
                    default:
                        spi_slave_queue_trans(RCV_HOST, transaction, 1)  ;                      
				}
				state = STATE_WAIT_XFER;
				break;
		}
        
        switch (wifi_status.state) {
            case WIFI_IDLE:
                if (strlen(ssid) > 0) {
                    wifi_status.state = WIFI_CONNECT;
                }
                break;
                
            case WIFI_CONNECT:
                wifi_config_t wifi_config = { 0 };
                esp_wifi_stop();
                strcpy((char *)wifi_config.sta.ssid, ssid);
                strcpy((char *)wifi_config.sta.password, psk);	
                esp_wifi_set_config(WIFI_IF_STA, &wifi_config);
                esp_wifi_start();
                esp_wifi_connect();
                wifi_status.state = WIFI_CONNECTING;
                break;
                
            case WIFI_CONNECTING:
                break;
                
            case WIFI_CONNECTED:
                // This is where we read and write packets
                break;

            case WIFI_DISCONNECTED:
                wifi_status.state = WIFI_CONNECT;
                break;
        }
        
        
        
    }
}

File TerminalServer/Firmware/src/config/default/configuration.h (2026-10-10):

/*******************************************************************************
  System Configuration Header

  File Name:
    configuration.h

  Summary:
    Build-time configuration header for the system defined by this project.

  Description:
    An MPLAB Project may have multiple configurations.  This file defines the
    build-time options for a single configuration.

  Remarks:
    This configuration header must not define any prototypes or data
    definitions (or include any files that do).  It only provides macro
    definitions for build-time configuration options

*******************************************************************************/

// DOM-IGNORE-BEGIN
/*******************************************************************************
* Copyright (C) 2018 Microchip Technology Inc. and its subsidiaries.
*
* Subject to your compliance with these terms, you may use Microchip software
* and any derivatives exclusively with Microchip products. It is your
* responsibility to comply with third party license terms applicable to your
* use of third party software (including open source software) that may
* accompany Microchip software.
*
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
* IN NO EVENT WILL MICROCHIP BE LIABLE FOR ANY INDIRECT, SPECIAL, PUNITIVE,
* INCIDENTAL OR CONSEQUENTIAL LOSS, DAMAGE, COST OR EXPENSE OF ANY KIND
* WHATSOEVER RELATED TO THE SOFTWARE, HOWEVER CAUSED, EVEN IF MICROCHIP HAS
* BEEN ADVISED OF THE POSSIBILITY OR THE DAMAGES ARE FORESEEABLE. TO THE
* FULLEST EXTENT ALLOWED BY LAW, MICROCHIP'S TOTAL LIABILITY ON ALL CLAIMS IN
* ANY WAY RELATED TO THIS SOFTWARE WILL NOT EXCEED THE AMOUNT OF FEES, IF ANY,
* THAT YOU HAVE PAID DIRECTLY TO MICROCHIP FOR THIS SOFTWARE.
*******************************************************************************/
// DOM-IGNORE-END

#ifndef CONFIGURATION_H
#define CONFIGURATION_H

// *****************************************************************************
// *****************************************************************************
// Section: Included Files
// *****************************************************************************
// *****************************************************************************
/*  This section Includes other configuration headers necessary to completely
    define this configuration.
*/

#include "user.h"
#include "device.h"

// DOM-IGNORE-BEGIN
#ifdef __cplusplus  // Provide C++ Compatibility

extern "C" {

#endif
// DOM-IGNORE-END

// *****************************************************************************
// *****************************************************************************
// Section: System Configuration
// *****************************************************************************
// *****************************************************************************



// *****************************************************************************
// *****************************************************************************
// Section: System Service Configuration
// *****************************************************************************
// *****************************************************************************
/* TIME System Service Configuration Options */
#define SYS_TIME_INDEX_0                            (0)
#define SYS_TIME_MAX_TIMERS                         (5)
#define SYS_TIME_HW_COUNTER_WIDTH                   (32)
#define SYS_TIME_HW_COUNTER_PERIOD                  (4294967295U)
#define SYS_TIME_HW_COUNTER_HALF_PERIOD             (SYS_TIME_HW_COUNTER_PERIOD>>1)
#define SYS_TIME_CPU_CLOCK_FREQUENCY                (80000000)
#define SYS_TIME_COMPARE_UPDATE_EXECUTION_CYCLES    (460)


/* File System Service Configuration */

#define SYS_FS_MEDIA_NUMBER               (1U)
#define SYS_FS_VOLUME_NUMBER              (1U)

#define SYS_FS_AUTOMOUNT_ENABLE           true
#define SYS_FS_CLIENT_NUMBER              4U
#define SYS_FS_MAX_FILES                  (6U)
#define SYS_FS_MAX_FILE_SYSTEM_TYPE       (1U)
#define SYS_FS_MEDIA_MAX_BLOCK_SIZE       (512U)
#define SYS_FS_MEDIA_MANAGER_BUFFER_SIZE  (2048U)
#define SYS_FS_USE_LFN                    (1)
#define SYS_FS_FILE_NAME_LEN              (255U)
#define SYS_FS_CWD_STRING_LEN             (1024)

/* File System RTOS Configurations*/
#define SYS_FS_STACK_SIZE                 1024
#define SYS_FS_PRIORITY                   1

#define SYS_FS_FAT_VERSION                "v0.15"
#define SYS_FS_FAT_READONLY               false
#define SYS_FS_FAT_CODE_PAGE              437
#define SYS_FS_FAT_MAX_SS                 SYS_FS_MEDIA_MAX_BLOCK_SIZE





#define SYS_FS_MEDIA_TYPE_IDX0 				SYS_FS_MEDIA_TYPE_SD_CARD
#define SYS_FS_TYPE_IDX0 					FAT

#define SYS_FS_MEDIA_IDX0_MOUNT_NAME_VOLUME_IDX0 			"/mnt/sd"
#define SYS_FS_MEDIA_IDX0_DEVICE_NAME_VOLUME_IDX0			"/dev/mmcblka1"
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

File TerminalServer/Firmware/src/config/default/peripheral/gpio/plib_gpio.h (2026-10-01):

/*******************************************************************************
  GPIO PLIB

  Company:
    Microchip Technology Inc.

  File Name:
    plib_gpio.h

  Summary:
    GPIO PLIB Header File

  Description:
    This library provides an interface to control and interact with Parallel
    Input/Output controller (GPIO) module.

*******************************************************************************/

/*******************************************************************************
* Copyright (C) 2019 Microchip Technology Inc. and its subsidiaries.
*
* Subject to your compliance with these terms, you may use Microchip software
* and any derivatives exclusively with Microchip products. It is your
* responsibility to comply with third party license terms applicable to your
* use of third party software (including open source software) that may
* accompany Microchip software.
*
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
* IN NO EVENT WILL MICROCHIP BE LIABLE FOR ANY INDIRECT, SPECIAL, PUNITIVE,
* INCIDENTAL OR CONSEQUENTIAL LOSS, DAMAGE, COST OR EXPENSE OF ANY KIND
* WHATSOEVER RELATED TO THE SOFTWARE, HOWEVER CAUSED, EVEN IF MICROCHIP HAS
* BEEN ADVISED OF THE POSSIBILITY OR THE DAMAGES ARE FORESEEABLE. TO THE
* FULLEST EXTENT ALLOWED BY LAW, MICROCHIP'S TOTAL LIABILITY ON ALL CLAIMS IN
* ANY WAY RELATED TO THIS SOFTWARE WILL NOT EXCEED THE AMOUNT OF FEES, IF ANY,
* THAT YOU HAVE PAID DIRECTLY TO MICROCHIP FOR THIS SOFTWARE.
*******************************************************************************/

#ifndef PLIB_GPIO_H
#define PLIB_GPIO_H

#include <device.h>
#include <stdint.h>
#include <stdbool.h>
#include <stddef.h>

// DOM-IGNORE-BEGIN
#ifdef __cplusplus  // Provide C++ Compatibility

    extern "C" {

#endif
// DOM-IGNORE-END

// *****************************************************************************
// *****************************************************************************
// Section: Data types and constants
// *****************************************************************************
// *****************************************************************************


/*** Macros for FRES pin ***/
#define FRES_Set()               (LATGSET = (1<<15))
#define FRES_Clear()             (LATGCLR = (1<<15))
#define FRES_Toggle()            (LATGINV= (1<<15))
#define FRES_OutputEnable()      (TRISGCLR = (1<<15))
#define FRES_InputEnable()       (TRISGSET = (1<<15))
#define FRES_Get()               ((PORTG >> 15) & 0x1)
#define FRES_GetLatch()          ((LATG >> 15) & 0x1)
#define FRES_PIN                  GPIO_PIN_RG15

/*** Macros for U6DTR pin ***/
#define U6DTR_Set()               (LATESET = (1<<5))
#define U6DTR_Clear()             (LATECLR = (1<<5))
#define U6DTR_Toggle()            (LATEINV= (1<<5))
#define U6DTR_OutputEnable()      (TRISECLR = (1<<5))
#define U6DTR_InputEnable()       (TRISESET = (1<<5))
#define U6DTR_Get()               ((PORTE >> 5) & 0x1)
#define U6DTR_GetLatch()          ((LATE >> 5) & 0x1)
#define U6DTR_PIN                  GPIO_PIN_RE5

/*** Macros for U6RTS pin ***/
#define U6RTS_Set()               (LATESET = (1<<6))
#define U6RTS_Clear()             (LATECLR = (1<<6))
#define U6RTS_Toggle()            (LATEINV= (1<<6))
#define U6RTS_OutputEnable()      (TRISECLR = (1<<6))
#define U6RTS_InputEnable()       (TRISESET = (1<<6))
#define U6RTS_Get()               ((PORTE >> 6) & 0x1)
#define U6RTS_GetLatch()          ((LATE >> 6) & 0x1)
#define U6RTS_PIN                  GPIO_PIN_RE6

/*** Macros for U3SHTDN pin ***/
#define U3SHTDN_Set()               (LATESET = (1<<7))
#define U3SHTDN_Clear()             (LATECLR = (1<<7))
#define U3SHTDN_Toggle()            (LATEINV= (1<<7))
#define U3SHTDN_OutputEnable()      (TRISECLR = (1<<7))
#define U3SHTDN_InputEnable()       (TRISESET = (1<<7))
#define U3SHTDN_Get()               ((PORTE >> 7) & 0x1)
#define U3SHTDN_GetLatch()          ((LATE >> 7) & 0x1)
#define U3SHTDN_PIN                  GPIO_PIN_RE7

/*** Macros for U3STATUS pin ***/
#define U3STATUS_Set()               (LATCSET = (1<<1))
#define U3STATUS_Clear()             (LATCCLR = (1<<1))
#define U3STATUS_Toggle()            (LATCINV= (1<<1))
#define U3STATUS_OutputEnable()      (TRISCCLR = (1<<1))
#define U3STATUS_InputEnable()       (TRISCSET = (1<<1))
#define U3STATUS_Get()               ((PORTC >> 1) & 0x1)
#define U3STATUS_GetLatch()          ((LATC >> 1) & 0x1)
#define U3STATUS_PIN                  GPIO_PIN_RC1

/*** Macros for U3CTS pin ***/
#define U3CTS_Set()               (LATCSET = (1<<2))
#define U3CTS_Clear()             (LATCCLR = (1<<2))
#define U3CTS_Toggle()            (LATCINV= (1<<2))
#define U3CTS_OutputEnable()      (TRISCCLR = (1<<2))
#define U3CTS_InputEnable()       (TRISCSET = (1<<2))
#define U3CTS_Get()               ((PORTC >> 2) & 0x1)
#define U3CTS_GetLatch()          ((LATC >> 2) & 0x1)
#define U3CTS_PIN                  GPIO_PIN_RC2
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

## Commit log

2026-02-07 Initial import
    [MTJ-88ARX1-LH.igs, QFN-24.iges, TerminalServer.kicad_pcb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]
2026-02-24 Almost complete
    [553-0121F.stp, DC_Power_Jack_PCB_Mounted_2.1mm.step, DUAL LED HOUSING 3mm.stp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]
2026-02-26 Added Ethernet and more
    [08B0-1D1T-06-F.stp, SI-60118-F.stp, SSF-LXH340LYGID.stp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]
2026-02-27 Added 4-led module
    [TerminalServer.kicad_pcb, TerminalServer.kicad_sch]
2026-03-01 Improved render interface
    [TerminalServer.kicad_pcb]
2026-05-15 Added SD card
    [TerminalServer.kicad_pcb, TerminalServer.kicad_sch]
2026-05-28 Final cleanup
    [12401610E4#2A.stl, 12401610E4#2A.stp, 217175-0001.stl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]
2026-05-29 Reverted to quad LED
    [TerminalServer.kicad_pcb, TerminalServer.kicad_sch]
2026-08-05 Initial firmware work
    [TerminalServer.kicad_pcb, TerminalServer.kicad_sch, configuration.h]
2026-08-10 Working on UART interface
2026-08-17 Basic working UART
2026-09-13 Massive progress on firmware
    [configuration.h]
2026-09-18 Recovered from MPLAB-X screwup
    [configuration.h]
2026-09-19 Working ZeroConf
    [configuration.h]
2026-09-20 TCP_IN and now single-threaded operation for more stability
    [configuration.h]
2026-09-20 Switched to internal pin control system
2026-09-20 Switch to internal StreamBuffer objects instead of custom circular buffers
2026-09-21 Now with added bootloader
    [configuration.h]
2026-09-23 Housekeeping and IDE data updates
    [configuration.h]
2026-09-23 Tie A2 of EEPROM high and move RS232 driver SHUTDOWN (now tied high) to ONLINE pin.
    [TerminalServer.kicad_pcb, TerminalServer.kicad_sch]
2026-09-24 Fixes to mDNS system
    [configuration.h]
2026-09-25 Ripped out MCHP zeroconf and wrote my own.
    [configuration.h]
2026-09-26 Working on SPI comms with ESP32
    [configuration.h]
2026-10-01 Implemented INT pin checking for ENC28J60
2026-10-01 Added INT pin for PHY status checks too
2026-10-01 Working (but a little slow?) WiFi
    [configuration.h]
2026-10-01 Faster and more stable WiFi
    [configuration.h]
2026-10-10 Some performance tweaks
    [configuration.h]
2026-10-10 Ability to mount TU58 file to port
